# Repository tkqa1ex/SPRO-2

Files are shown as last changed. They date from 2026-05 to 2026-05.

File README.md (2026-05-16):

# SPRO-2: Motor Control & Generator Project

## 🟦 Project Overview
This repository contains the hardware designs and firmware for our university semester project (SPRO-2).

---

## 📂 Repository Structure

### 🔌 [Hardware](./motor-PCB)
The hardware is designed in **KiCad** and is split into three main modules:
* **Control Board:** The "brains" of the operation, handling logic and signal processing.
* **Generator Board:** Responsible for power generation and distribution.
* **Current Sensor Test Board:** A dedicated board for validating the current sensing circuitry before full integration.

### 💻 [Firmware](./Firmware)
*(Coming Soon)*
The firmware will handle the motor control algorithms, sensor data acquisition, and communication logic.

---

## 🛠 Tech Stack
* **PCB Design:** KiCad 10.0
* **Firmware:** C / Arduino
* **Documentation:** LaTeX

---

## 👥 Team Members
* **Alexander (tkqa1ex)**
* **David (floppy)**
* [Name 3] - [Role]

---

## 🚀 Getting Started
1. **Clone the repo:**
   ```bash
   git clone [https://github.com/tkqa1ex/SPRO-2.git](https://github.com/tkqa1ex/SPRO-2.git)

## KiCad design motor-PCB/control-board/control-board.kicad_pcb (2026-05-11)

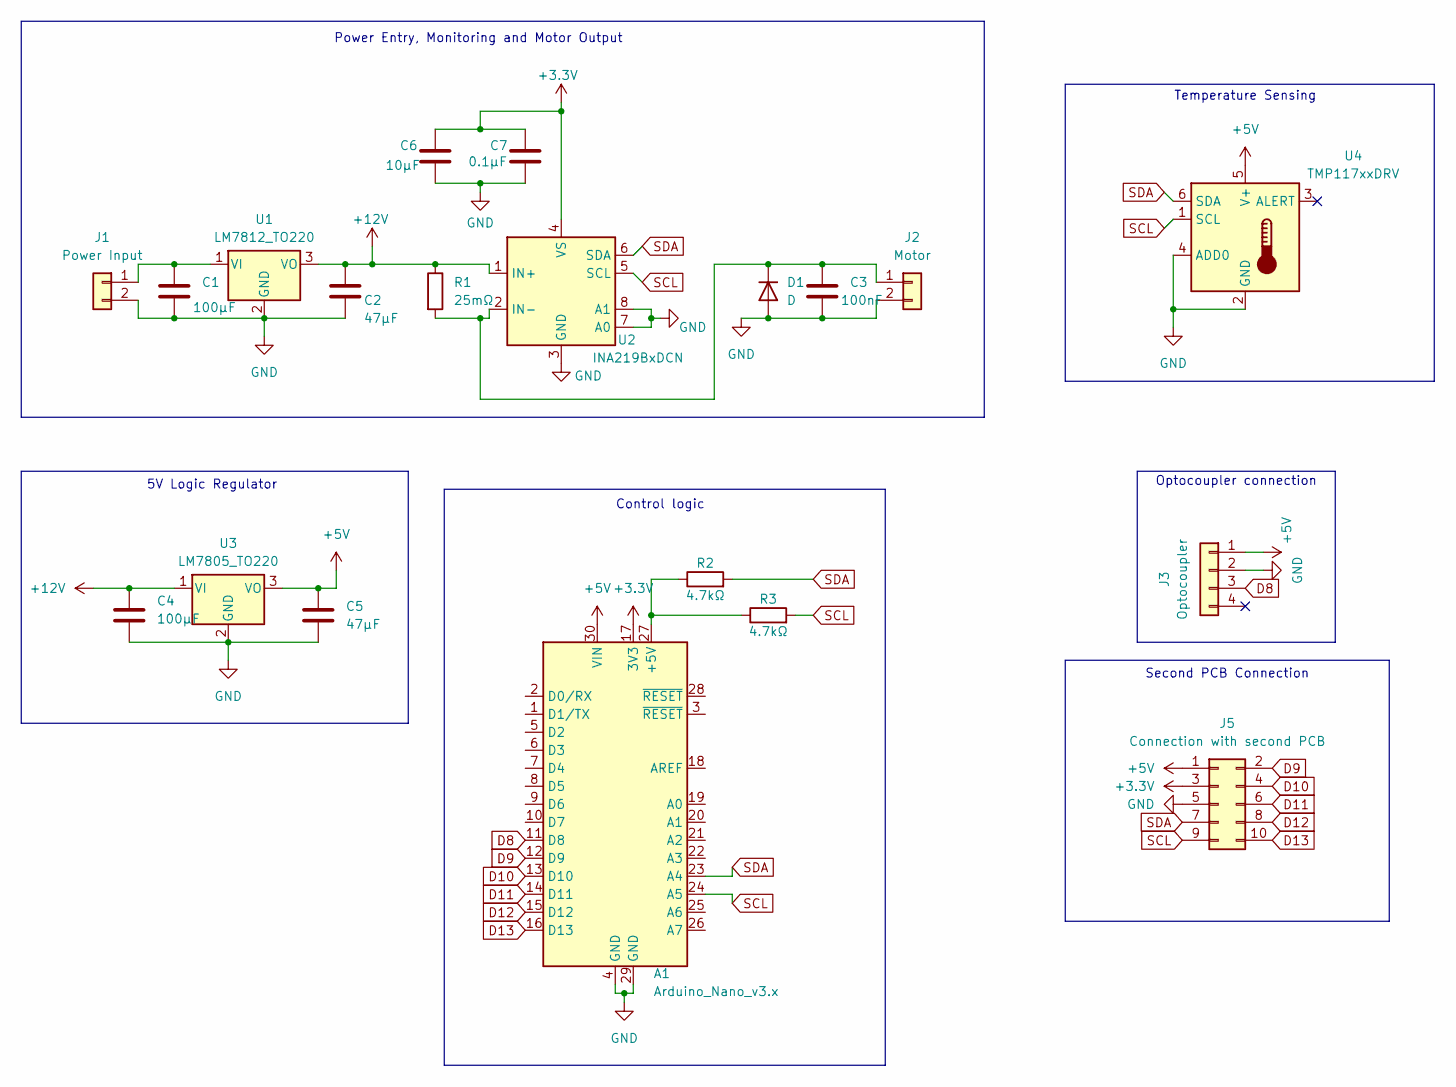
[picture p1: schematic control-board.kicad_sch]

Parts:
A1: Arduino_Nano_v3.x; Arduino_Nano
C1, C4: 100µF; CP_Radial_D8.0mm_P3.50mm
C2, C5: 47µF; CP_Radial_D6.3mm_P2.50mm
C3: 100nF; C_Disc_D5.0mm_W2.5mm_P2.50mm
C6: 10µF; CP_Radial_D5.0mm_P2.00mm
C7: 0.1µF; C_Disc_D5.0mm_W2.5mm_P2.50mm
D1: D; D_DO-41_SOD81_P10.16mm_Horizontal
J1: Power Input; TerminalBlock_CUI_TB007-508-02_1x02_P5.08mm_Horizontal
J2: Motor; TerminalBlock_CUI_TB007-508-02_1x02_P5.08mm_Horizontal
J3: Optocoupler; PinHeader_1x04_P2.54mm_Vertical
J5: Connection with second PCB; PinHeader_2x05_P2.54mm_Vertical
R1: 25mΩ; R_Axial_DIN0414_L11.9mm_D4.5mm_P15.24mm_Horizonta
R2: 4.7kΩ; R_Axial_DIN0207_L6.3mm_D2.5mm_P10.16mm_Horizontal
R3: 4.7kΩ; R_Axial_DIN0207_L6.3mm_D2.5mm_P7.62mm_Horizontal
U1: LM7812_TO220; TO-220-3_Vertical
U2: INA219BxDCN; SOT-23-8
U3: LM7805_TO220; TO-220-3_Vertical
U4: TMP117xxDRV; WSON-6-1EP_2x2mm_P0.65mm_EP1x1.6mm

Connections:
+3.3V: A1.17 (3V3), C6.1, C7.1, J5.3, U2.4 (VS)
+5V: A1.30 (VIN), C5.1, J3.1, J5.1, U3.3 (VO), U4.5 (V+)
+12V: C2.1, C4.1, R1.1, U1.3 (VO), U2.1 (IN+), U3.1 (VI)
D8: A1.11 (D8), J3.3
D9: A1.12 (D9), J5.2
D10: A1.13 (D10), J5.4
D11: A1.14 (D11), J5.6
D12: A1.15 (D12), J5.8
D13: A1.16 (D13), J5.10
GND: A1.4 (GND), A1.29 (GND), C1.2, C2.2, C3.2, C4.2, C5.2, C6.2, C7.2, D1.2 (A), J1.2, J2.2, J3.2, J5.5, U1.2 (GND), U2.3 (GND), U2.7 (A0), U2.8 (A1), U3.2 (GND), U4.2 (GND), U4.4 (ADD0)
unnamed: A1.27 (+5V), R2.1, R3.1
unnamed: C3.1, D1.1 (K), J2.1, R1.2, U2.2 (IN-)
unnamed: C1.1, J1.1, U1.1 (VI)
SCL: A1.24 (A5), J5.9, R3.2, U2.5 (SCL), U4.1 (SCL)
SDA: A1.23 (A4), J5.7, R2.2, U2.6 (SDA), U4.6 (SDA)

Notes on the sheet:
Temperature Sensing
Control logic
Optocoupler connection
Power Entry, Monitoring and Motor Output
Second PCB Connection
5V Logic Regulator

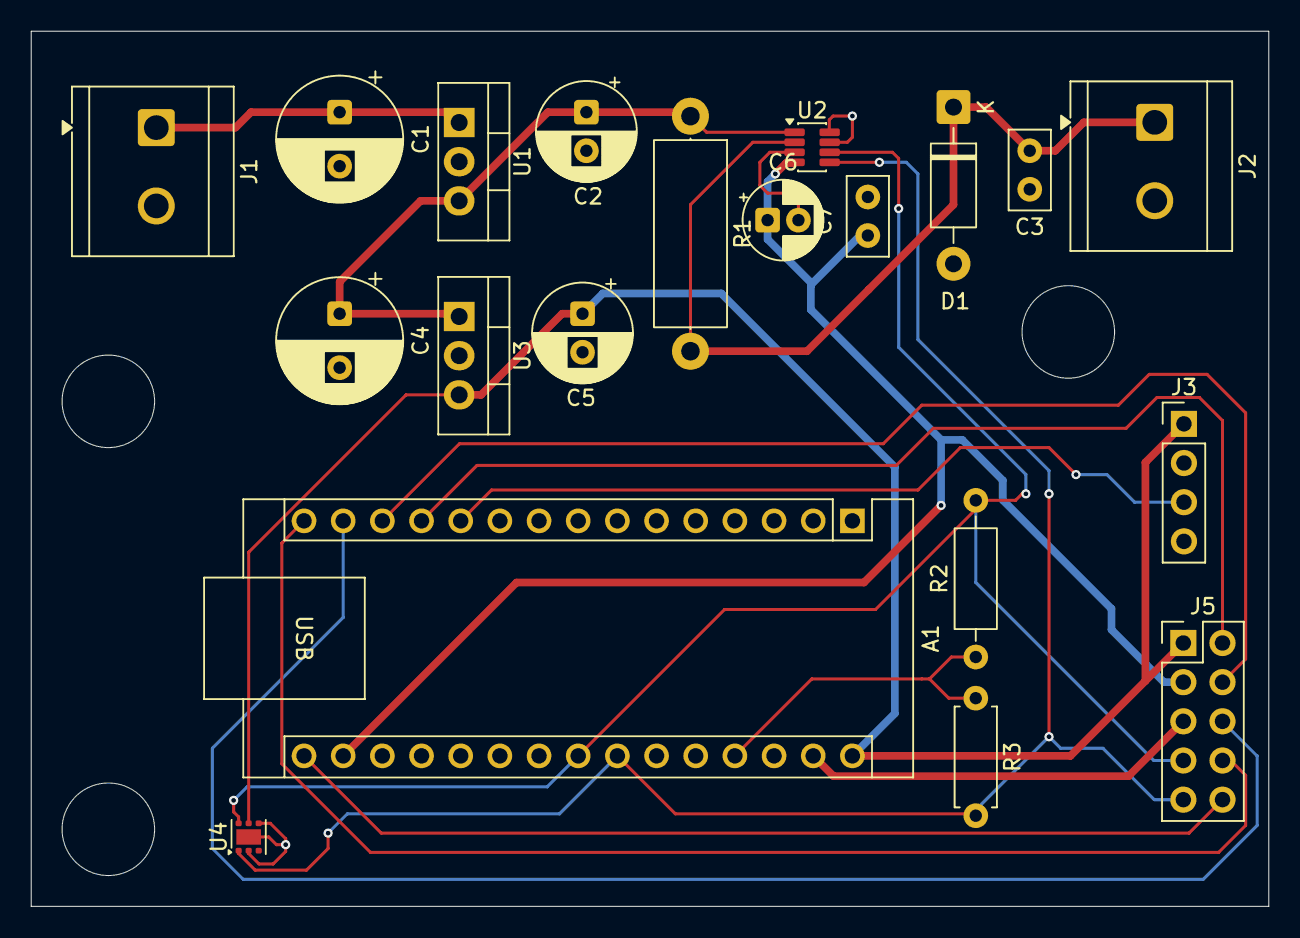
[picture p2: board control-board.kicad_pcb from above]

Board: 2 copper layers, 80.2 x 56.8 mm, 20 parts (0 on the bottom side), 15 nets.

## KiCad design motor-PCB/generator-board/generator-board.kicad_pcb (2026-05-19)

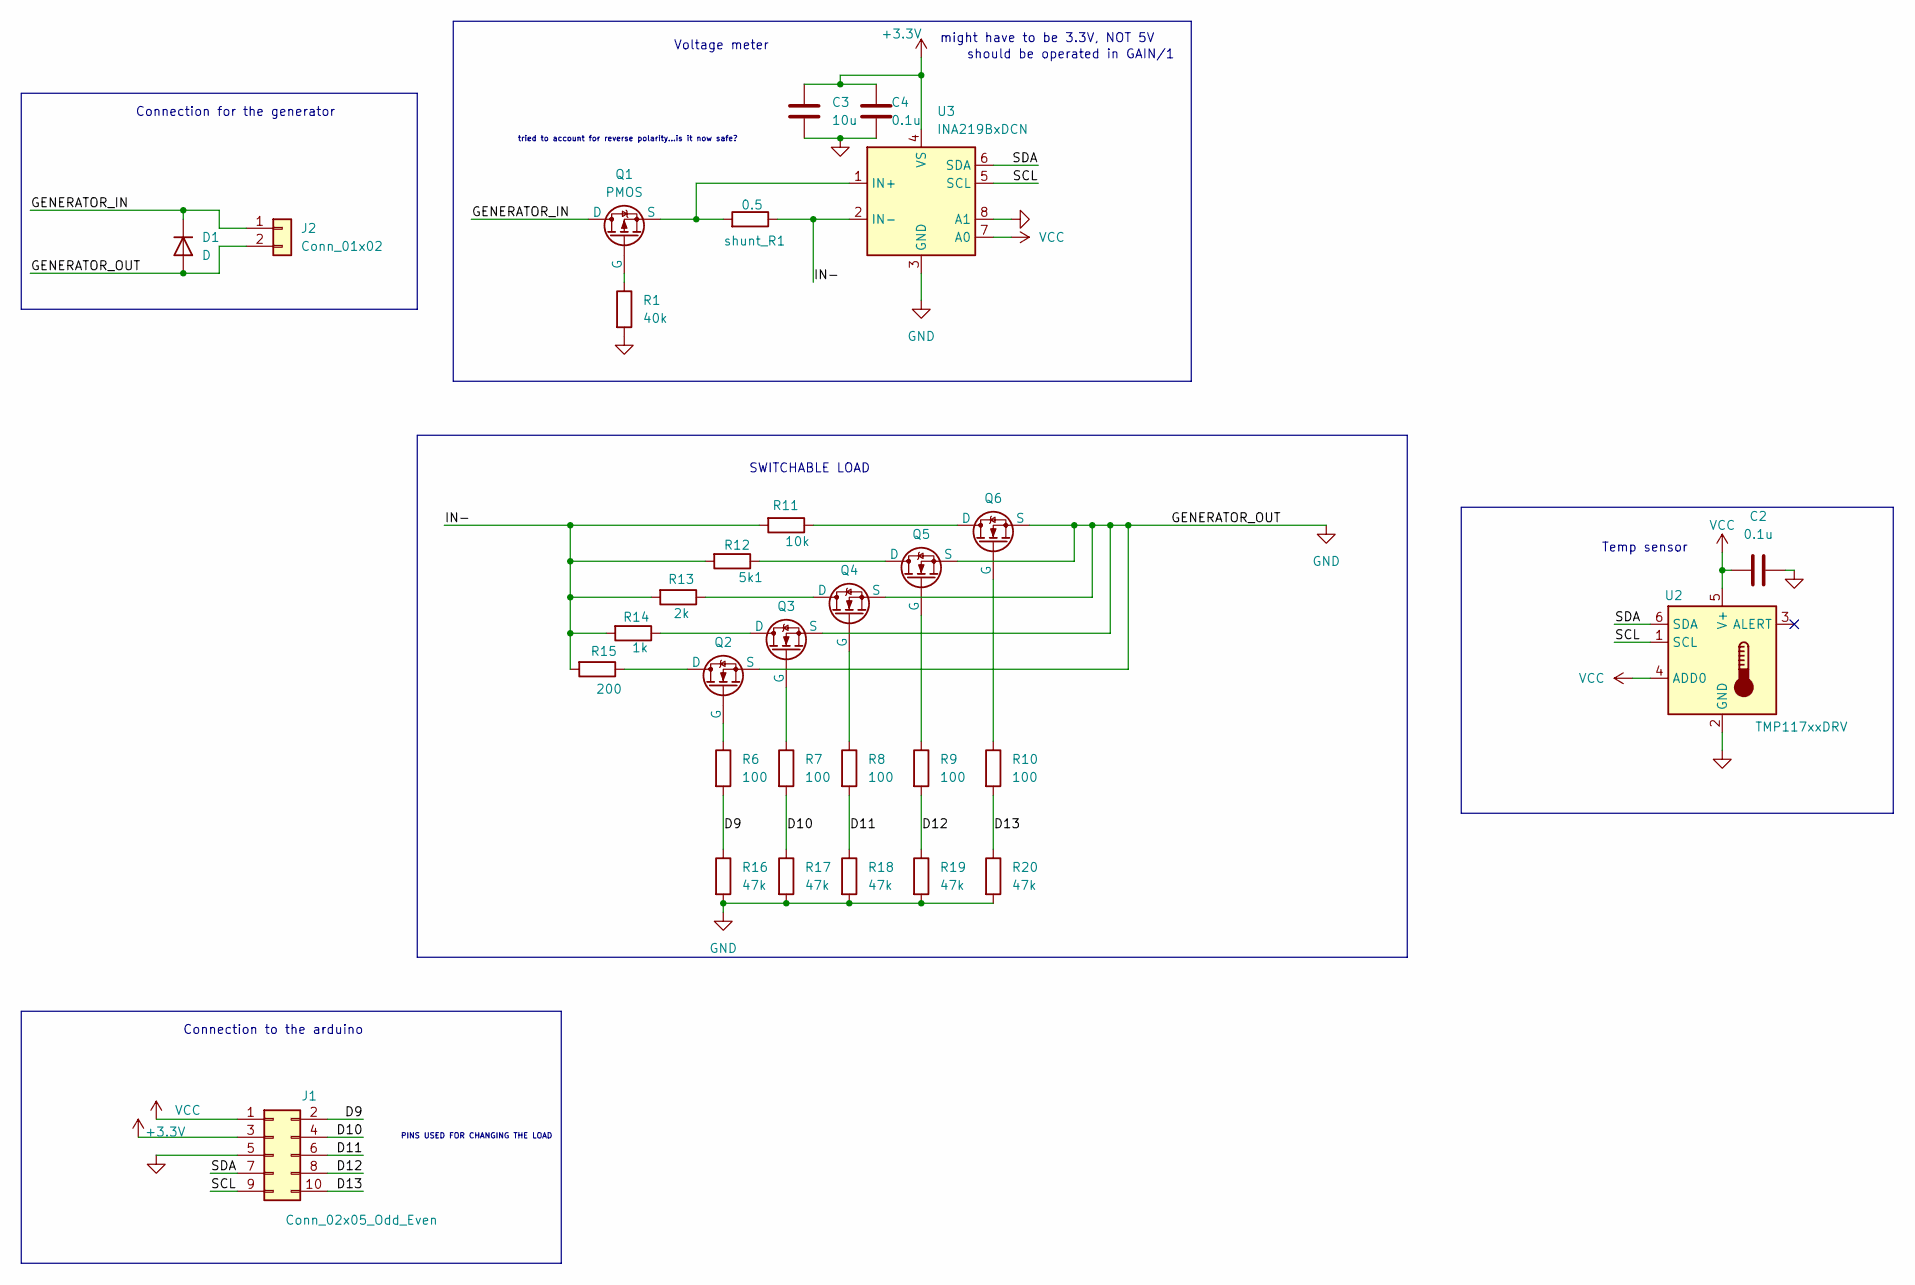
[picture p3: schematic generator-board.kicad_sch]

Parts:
C2, C4: 0.1u; CP_Radial_D10.0mm_P5.00mm
C3: 10u; CP_Radial_D10.0mm_P5.00mm
D1: D; D_DO-41_SOD81_P10.16mm_Horizontal
J1: Conn_02x05_Odd_Even; PinHeader_2x05_P2.54mm_Vertical
J2: Conn_01x02; PinHeader_1x02_P2.54mm_Vertical
Q1: PMOS; TO-220-3_Vertical
Q2, Q3, Q4, Q5, Q6: NMOS_GDS; TO-220-3_Vertical
R1: 40k; R_Axial_DIN0207_L6.3mm_D2.5mm_P10.16mm_Horizontal
R6, R7, R8, R9, R10: 100; R_Axial_DIN0207_L6.3mm_D2.5mm_P10.16mm_Horizontal
R11: 10k; R_Axial_DIN0207_L6.3mm_D2.5mm_P10.16mm_Horizontal
R12: 5k1; R_Axial_DIN0207_L6.3mm_D2.5mm_P10.16mm_Horizontal
R13: 2k; R_Axial_DIN0207_L6.3mm_D2.5mm_P10.16mm_Horizontal
R14: 1k; R_Axial_DIN0207_L6.3mm_D2.5mm_P10.16mm_Horizontal
R15: 200; R_Axial_DIN0207_L6.3mm_D2.5mm_P10.16mm_Horizontal
R16, R17, R18, R19, R20: 47k; R_Axial_DIN0207_L6.3mm_D2.5mm_P10.16mm_Horizontal
U2: TMP117xxDRV; WSON-6-1EP_2x2mm_P0.65mm_EP1x1.6mm
U3: INA219BxDCN; SOT-23-8
shunt_R1: 0.5; R_Axial_DIN0207_L6.3mm_D2.5mm_P10.16mm_Horizontal

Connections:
+3.3V: C3.1, C4.1, J1.3, U3.4 (VS)
/D9: J1.2, R6.2, R16.1
/D10: J1.4, R7.2, R17.1
/D11: J1.6, R8.2, R18.1
/D12: J1.8, R9.2, R19.1
/D13: J1.10, R10.2, R20.1
/GENERATOR_IN: D1.1 (K), J2.1, Q1.2 (D)
/IN-: R11.2, R12.2, R13.2, R14.2, R15.2, U3.2 (IN-), shunt_R1.1
/SCL: J1.9, U2.1 (SCL), U3.5 (SCL)
/SDA: J1.7, U2.6 (SDA), U3.6 (SDA)
GND: C2.2, C3.2, C4.2, D1.2 (A), J1.5, J2.2, Q2.3 (S), Q3.3 (S), Q4.3 (S), Q5.3 (S), Q6.3 (S), R1.2, R16.2, R17.2, R18.2, R19.2, R20.2, U2.2 (GND), U3.3 (GND), U3.8 (A1)
unnamed: Q1.1 (G), R1.1
unnamed: Q1.3 (S), U3.1 (IN+), shunt_R1.2
unnamed: Q2.2 (D), R15.1
unnamed: Q2.1 (G), R6.1
unnamed: Q3.2 (D), R14.1
unnamed: Q3.1 (G), R7.1
unnamed: Q4.2 (D), R13.1
unnamed: Q4.1 (G), R8.1
unnamed: Q5.2 (D), R12.1
unnamed: Q5.1 (G), R9.1
unnamed: Q6.2 (D), R11.1
unnamed: Q6.1 (G), R10.1
VCC: C2.1, J1.1, U2.4 (ADD0), U2.5 (V+), U3.7 (A0)

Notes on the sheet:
Voltage meter
tried to account for reverse polarity...is it now safe?
might have to be 3.3V, NOT 5V
Temp sensor
SWITCHABLE LOAD
Connection for the generator
should be operated in GAIN/1
Connection to the arduino
PINS USED FOR CHANGING THE LOAD

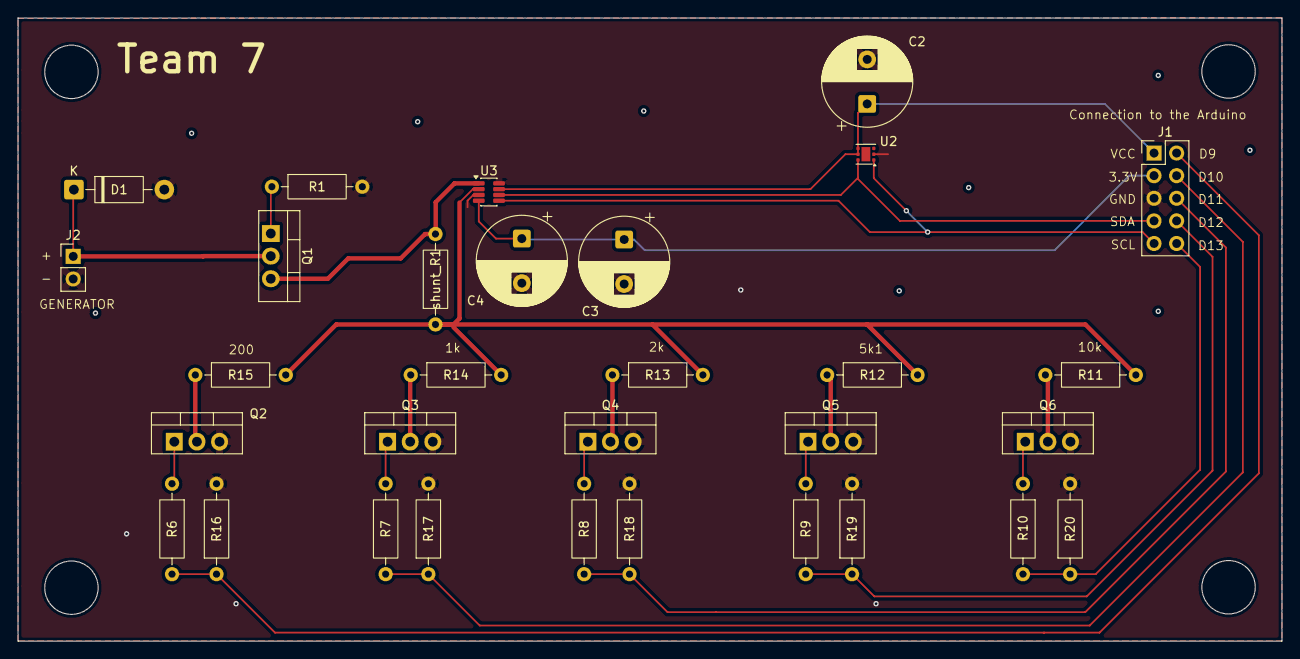
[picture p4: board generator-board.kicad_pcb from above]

Board: 2 copper layers, 142.0 x 70.0 mm, 31 parts (0 on the bottom side), 24 nets.

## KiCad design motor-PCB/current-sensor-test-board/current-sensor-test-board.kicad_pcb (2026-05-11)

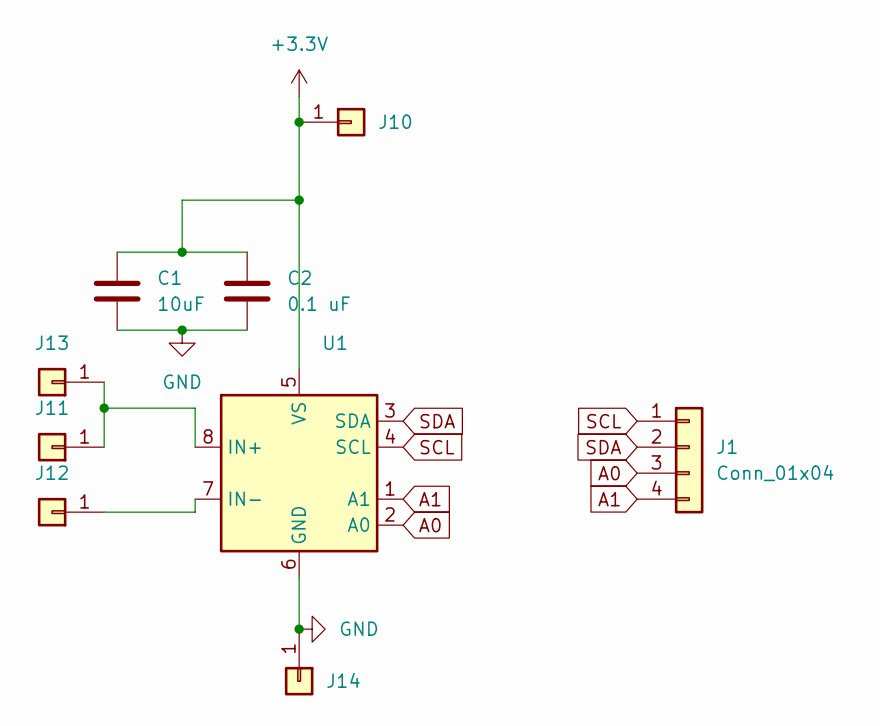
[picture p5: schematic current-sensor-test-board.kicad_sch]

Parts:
C1: 10uF; CP_Radial_D5.0mm_P2.00mm
C2: 0.1 uF; C_Disc_D5.0mm_W2.5mm_P2.50mm
J1: Conn_01x04; PinHeader_1x04_P2.54mm_Vertical
J10, J13, J14: Conn_01x01; PinHeader_1x01_P2.54mm_Vertical
J11, J12: Conn_01x01; PinSocket_1x01_P2.54mm_Vertical
U1: INA219AxD; SOIC-8_3.9x4.9mm_P1.27mm

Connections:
+3.3V: C1.2, C2.1, J10.1 (Pin_1_1), U1.5 (VS)
A0: J1.3, U1.2 (A0)
A1: J1.4, U1.1 (A1)
GND: C1.1, C2.2, J14.1 (Pin_1_1), U1.6 (GND)
unnamed: J11.1 (Pin_1_1), J13.1 (Pin_1_1), U1.8 (IN+)
unnamed: J12.1 (Pin_1_1), U1.7 (IN-)
SCL: J1.1, U1.4 (SCL)
SDA: J1.2, U1.3 (SDA)

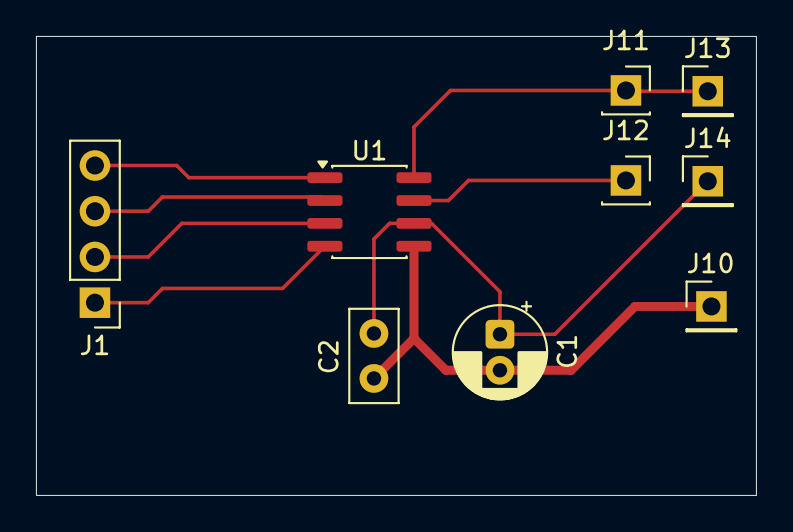
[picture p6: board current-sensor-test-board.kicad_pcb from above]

Board: 2 copper layers, 40.0 x 25.5 mm, 9 parts (0 on the bottom side), 8 nets.

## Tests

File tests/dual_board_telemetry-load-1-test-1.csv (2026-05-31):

Ctrl_Voltage_V | Ctrl_Current_mA | Ctrl_Temp_C | Gen_Voltage_V | Gen_Current_mA | Gen_Temp_C | RPM | I_mA_0 | T
1.88 | 249.2 | 27.55 | 0.02 | -0.03 | 24.52 | 4.166667 | 35.752167 | 1.325292 | 0
1.89 | 249.2 | 27.55 | 0.02 | -0.02 | 24.52 | 4.166667 | 35.752167 | 1.325663 | 0
1.9 | 250 | 27.55 | 0.02 | -0.02 | 24.52 | 4.166667 | 35.752167 | 1.325663 | 0
1.9 | 249.6 | 27.55 | 0.02 | -0.02 | 24.52 | 4.166667 | 35.752167 | 1.325663 | 0
5.19 | 336.4 | 27.55 | 4.17 | 11.34 | 24.52 | 868.75 | 39.2105 | 1.875424 | 0
7.6 | 372.8 | 27.56 | 8.6 | 33.77 | 24.52 | 1791.666667 | 42.902167 | 2.844537 | 0
8.61 | 364.4 | 27.56 | 11.08 | 48.5 | 24.52 | 2308.333333 | 44.968833 | 3.467694 | 0
8.69 | 359.6 | 27.56 | 11.27 | 50.64 | 24.52 | 2347.916667 | 45.127167 | 3.552962 | 0
10.06 | 419.2 | 27.56 | 12.33 | 52.62 | 24.52 | 2568.75 | 46.0105 | 3.659192 | 0
11.31 | 450.4 | 27.57 | 15.14 | 64.74 | 24.52 | 3154.166667 | 48.352167 | 4.195719 | 0
11.94 | 437.6 | 27.57 | 16.32 | 74.18 | 24.52 | 3400 | 49.3355 | 4.582425 | 0
11.95 | 436.4 | 27.57 | 16.51 | 74.47 | 24.52 | 3439.583333 | 49.493833 | 4.599058 | 0
11.93 | 434.8 | 27.57 | 16.53 | 74.56 | 24.52 | 3443.75 | 49.5105 | 4.603016 | 0
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

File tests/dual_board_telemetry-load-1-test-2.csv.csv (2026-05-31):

Ctrl_Voltage_V | Ctrl_Current_mA | Ctrl_Temp_C | Gen_Voltage_V | Gen_Current_mA | Gen_Temp_C | RPM | I_mA_0 | T
1.95 | 240.4 | 25.98 | 0.02 | -0.02 | 24.62 | 4.166667 | 35.752167 | 1.325663 | 0
1.94 | 240.4 | 25.98 | 0.02 | -0.02 | 24.62 | 4.166667 | 35.752167 | 1.325663 | 0
1.94 | 240.4 | 25.98 | 0.02 | -0.03 | 24.62 | 4.166667 | 35.752167 | 1.325292 | 0
1.94 | 240.4 | 25.98 | 0.02 | -0.02 | 24.62 | 4.166667 | 35.752167 | 1.325663 | 0
1.95 | 240.4 | 25.98 | 0.02 | -0.02 | 24.62 | 4.166667 | 35.752167 | 1.325663 | 0
1.95 | 240.4 | 25.97 | 0.02 | -0.03 | 24.62 | 4.166667 | 35.752167 | 1.325292 | 0
1.94 | 240.4 | 25.97 | 0.02 | -0.02 | 24.62 | 4.166667 | 35.752167 | 1.325663 | 0
1.95 | 240.4 | 25.97 | 0.02 | -0.03 | 24.62 | 4.166667 | 35.752167 | 1.325292 | 0
1.94 | 240.4 | 25.97 | 0.02 | -0.02 | 24.62 | 4.166667 | 35.752167 | 1.325663 | 0
1.96 | 241.2 | 25.97 | 0.02 | -0.03 | 24.62 | 4.166667 | 35.752167 | 1.325292 | 0
2.23 | 241.6 | 25.97 | 0.02 | -0.02 | 24.62 | 4.166667 | 35.752167 | 1.325663 | 0
9.13 | 485.2 | 25.97 | 7.78 | 47.65 | 24.62 | 1620.833333 | 42.218833 | 3.334134 | 0
9.33 | 364.4 | 25.97 | 12.1 | 54.76 | 24.62 | 2520.833333 | 45.818833 | 3.731475 | 0
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

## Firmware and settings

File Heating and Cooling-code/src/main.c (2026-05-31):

#include <stdio.h>
#include <stdbool.h>
#include <avr/io.h>
#include <util/delay.h>
#include <avr/interrupt.h>
#include <string.h>
#include "usart.h"

#define DBS_TIME (uint32_t)10000

volatile float PWM_FAN = 0.5;
volatile float PWM_HEATING_PAD = 0.25;
volatile uint32_t last_fan_button_press,last_heating_pad_button_press;
volatile uint16_t tovf_cnt,fan_adc,heating_pad_adc;
volatile uint8_t last_fan_edge = 1,last_heating_pad_edge = 1,adc_conversion_complete;
volatile uint8_t change_pwm_fan = 1,change_pwm_heating_pad = 1;

// implement 2 pwms (hai T0 si T2 sa aiba aceeasi durata)
// check they work
// add PCINT to arduino and check with buttons
// beers?

void arduino_init(void);

// not used but nice to have in case u want to implement a PID controller
void set_heating_pad_PWM(float pwm);
void set_fan_PWM(float pwm);
void adjust_PWM();
void read_new_ADC();
uint16_t read_adc(int);

int main() {
    arduino_init();
    while (1) {
        // read the new voltages to figure out position of the pot
        // and change the pwm accordingly
        read_new_ADC();
        adjust_PWM();
        _delay_ms(300);
    }
}

// same structure for the PCINT2 ISR
ISR(PCINT0_vect) {
    // the real time at the time this interrupt was triggered
    uint32_t actual_time = ((uint32_t)tovf_cnt << 16) + TCNT1;

    // find what type of change has occured (1 means rising, 0 is falling)
    uint8_t current_edge = 0;
    if (PINB & (1 << PB1)) {
        current_edge = 1;
    }

    // only process the interrupt when the edge actually changes
    // noise can sometimes toggle the signal extremely quickly.
    //
    // for example
    // - last valid edge was HIGH
    // - noise briefly causes HIGH -> LOW -> HIGH within a few us
    // the temporary LOW transition is ignored by the debounce filter because it
    // occurs too soon after the previous HIGH edge. However, the second HIGH may
    // arrive later and still trigger a pin-change interrupt even though the
    // logical edge state never truly changed.
    if (last_fan_edge != current_edge) {
        // if it is on a rising edge and the time since the last press is more than the DBS_TIME 
        if (last_fan_edge == 1 && actual_time - last_fan_button_press >= DBS_TIME) {
            last_fan_button_press = actual_time;
            if (change_pwm_fan == 0) {
                change_pwm_fan = 1;
                OCR0B = PWM_FAN * 0xFF;
                TCCR0B |= (1 << CS01) | (1 << CS00); 
            } else {
                change_pwm_fan = 0;
                OCR0B = 0;
                TCCR0B = 0;
            }
        }
        last_fan_edge = current_edge;
    }
}

ISR(PCINT2_vect) {
    uint32_t actual_time = ((uint32_t)tovf_cnt << 16) + TCNT1;
    uint8_t current_edge = 0;
    if (PIND & (1 << PD6)) {
        current_edge = 1;
    }
    if (last_heating_pad_edge != current_edge) {
        if (last_heating_pad_edge == 1 && actual_time - last_heating_pad_button_press >= DBS_TIME) {
            last_heating_pad_button_press = actual_time;
            if (change_pwm_heating_pad == 0) {
                change_pwm_heating_pad = 1;
                TCCR2B |= (1 << CS22);
                OCR2B = PWM_HEATING_PAD * 0xFF;
            } else {
                change_pwm_heating_pad = 0;
                OCR2B = 0;
                TCCR2B = 0;
            }
        }
        last_heating_pad_edge = current_edge;
    }
}

ISR(TIMER1_OVF_vect) {
    ++tovf_cnt;
}

uint16_t read_adc(int channel) {
    ADMUX &= ~(0x0F);
    ADMUX |= channel;
    _delay_ms(10);
    ADCSRA |= (1 << ADSC);
    while (ADCSRA & (1 << ADSC));

    return ADC;
}
// gonna use ADC0-1 -> PC0-1 (A0-1)
void read_new_ADC() {
    fan_adc = read_adc(0);
    heating_pad_adc = read_adc(1);
}

void adjust_PWM() {
    // x - 100
    // ADC - 2^10
    set_fan_PWM(fan_adc / 1024.0);
    set_heating_pad_PWM(heating_pad_adc / 1024.0);
    //printf("FAN PWM: %.2f\n HEATING PAD PWM: %.2f \n\n",PWM_FAN,PWM_HEATING_PAD);
}

void set_heating_pad_PWM(float pwm) {
    PWM_HEATING_PAD = pwm;
    if (change_pwm_heating_pad) {
        OCR2B = 0xFF * pwm;
    }
}

void set_fan_PWM(float pwm) {
    PWM_FAN = pwm;
    if (change_pwm_fan) {
        OCR0B = 0xFF * pwm;
    }
}

void enable_ADC() {
    ADMUX |= (1 << REFS0);
    ADCSRA |= (1 << ADEN);
    ADCSRA |= (1 << ADPS2 | 1 << ADPS1 | 1 << ADPS0);
    // ADC has a resolution of 10 bits with 5V as VREF => we can use a 1k pot to change the pwm, nice :)
}

void init_timer() {
    // init timer1 with prescalar of 8 to get
    // 32ms
    TCCR1B |= (1 << CS11);
    //TOVF niterrupt
    TIMSK1 |= (1 << TOIE1);
}

void set_up_pwms() {
    // use fast pwm + toggle on compare match
    // gonna use OC0B with clear on equal
    // setting for OC0B -> PD5, CHECKED, click of button also CHECKED
    DDRD |= (1 << PD5);
    OCR0B = 0xFF * PWM_FAN;
    TCCR0A |= (1 << COM0B1) | (1 << WGM01) | (1 << WGM00);
    // scalar of 64 so every overflow is 1ms 
    TCCR0B |= (1 << CS01) | (1 << CS00); 
    

    // setting for 0C2B -> PD3, CHECKED
    DDRD |= (1 << PD3);
    OCR2B = 0xFF * PWM_HEATING_PAD;
    TCCR2A |= (1 << COM2B1) | (1 << WGM21 | 1 << WGM20);
    TCCR2B |= (1 << CS22);
}

void set_up_edge_detection() {
    // gonna use PCINT22 (PD6-D6),PCINT1(PB1-D9) 
    // 1 -> FAN (PB1)
    // 22 -> HEATING PAD (PD6)
    DDRB &= ~(1 << PB1);
    DDRD &= ~(1 << PD6);

    PORTB |= (1 << PB1);
    PORTD |= (1 << PD6);
    // enable the 2 and 0 group
    PCICR |= (1 << PCIE2) | (1 << PCIE0);
    PCMSK2 |= (1 << PCINT22);
    PCMSK0 |= (1 << PCINT1);
}

void arduino_init() {
    // initialise the communication to the pc for debugging purposes mainly
    uart_init();
    io_redirect();

    enable_ADC();
    init_timer();
    set_up_pwms();
    set_up_edge_detection();
    // enable interrupts
    sei();
}

// can use the pins to the generator to track the i2c bus
// the current has 16 bit contents



 

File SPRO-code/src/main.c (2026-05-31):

#include <stdio.h>
#include <stdbool.h>
#include <avr/io.h>
#include <util/delay.h>
#include <avr/interrupt.h>
#include <string.h>
#include "usart.h"
#include "i2cmaster.h"
#include "constants.h"
#include "INA219.h"
#include "TMP117.h"

volatile uint16_t counter;
volatile uint64_t timer;

// flag which makes sure the sampling rate is mantained 
volatile uint8_t take_data,stop_sending_data;

// for the data from the sensors
float bus_voltage_control,bus_voltage_generator,current_control,current_generator,
ambiental_temperature_control,ambiental_temperature_generator;



// start timer with precalar of 64 to get 1ms per counter overflow
void init_timer2();

// configure all the sensors through I2C
void init_outsiders();
void OPEN(pin LOAD);
void system_init(pin LOAD);

// used to get the needed data
void take_measurement();
void get_TMP117_CONTROL();
void get_TMP117_GENERATOR();
void get_INA219_GENERATOR();
void get_INA219_CONTROL();

// send data to the PC which reads it with matlab
void send_data_to_matlab();

int main() {
    // initialise the system whilst also opening pin D9
    system_init(D9);
    while (1) {
        // whenever the sampling time is reached take_data is set true by
        // a timer2 interrupt
        if (take_data) {
            // get all the measurements from the sensors
            take_measurement();

            // send everything through usart to 
            send_data_to_matlab();
            take_data = false;
        }
    }
}

void send_data_to_matlab() {
    // Sending to the PC data as follows
    // voltage control, current control, control temp
    // voltage generator, current generator, gen temp
    printf("%.2f %.2f %.2f %.2f %.2f %.2f %d\n",bus_voltage_control,current_control,ambiental_temperature_control,
        bus_voltage_generator,current_generator,ambiental_temperature_generator,
        stop_sending_data);

    // FOR DEBUGGING
    // printf("Control: bus voltage: %f V current: %f mA temperature: %fC\n",bus_voltage_control,current_control,ambiental_temperature_control);
    // printf("Generator: bus voltage: %f V current: %f mA temperature: %fC\n",bus_voltage_generator,current_generator,ambiental_temperature_generator);
    // printf("Loop flag: %u\n\n",stop_sending_data);
}

// init sensors
void init_outsiders() {
    INA219_INIT_CONTROL();
    INA219_INIT_GENERATOR();
    TMP117_INIT(TMP117_CONTROL);
    TMP117_INIT(TMP117_GENERATOR);
    // give enough time for components to wake up and transients to magically disappear, to fade away like my hopes and dreams :)))
    // just to make sure they have the time to update, shuold be much less but we arent rly in a worry
    _delay_ms(5); 
}

// get readings from the INA219 sensor from the generator
void get_INA219_GENERATOR() {
    bus_voltage_generator = GET_BUS_VOLTAGE(INA219_GENERATOR);
    current_generator = GET_CURRENT_GENERATOR();
}

// get readings from the TMP117 sensor from the generator
void get_TMP117_GENERATOR() {
    ambiental_temperature_generator = TMP117_readTemperature(TMP117_GENERATOR);
}

// get readings from the TMP117 sensor from the control
void get_TMP117_CONTROL() {
    ambiental_temperature_control = TMP117_readTemperature(TMP117_CONTROL);
}

// get readings from the INA219 sensor from the control
void get_INA219_CONTROL() {
    bus_voltage_control = GET_BUS_VOLTAGE(INA219_CONTROL); // seems to be overshoot by 0.2V
    current_control = GET_CURRENT_CONTROL();
}


// get the data from the sensors to the mcu
void take_measurement() {
    get_INA219_CONTROL();
    get_INA219_GENERATOR();
    get_TMP117_CONTROL();
    get_TMP117_GENERATOR();
}

void init_timer2() {
    // SCALAR OF 64, lasts 1ms
    // works in normal mode (it is the default) and its just a counter that gets back to 0 once it reaches max (0xFF)
    TIMSK2 |= (1 << TOIE2);
    TCCR2B |= (1 << CS22); 
}

void system_init(pin LOAD) {
    // enable interrupts
    sei(); 

    // debug + sending to matlab
    uart_init();
    io_redirect();

    // enable i2c communication
    i2c_init(); 

    // enable the load
    OPEN(LOAD);
    
    // init sensors
    init_outsiders();    
    
    // timer go brrr
    init_timer2();
}

void OPEN(pin LOAD) {
    // open the D9-D13 pin (PB1-5) resistor
    DDRB |= (1 << (LOAD + 1));
    PORTB |= (1 << (LOAD + 1));
}

// interrupts used for time counting
ISR(TIMER2_OVF_vect) {
    // every count is 1ms
    counter++;
    timer++;
    // to ensure the sampling rate
    if (counter == SAMPLING_RATE) {
        counter = 0;
        take_data = true;
    }
    if (timer == TESTING_TIME) {
        stop_sending_data = 1;
    }
}

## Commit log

2026-05-11 Initial commit: Added PCB folders and project structure
    [control-board.kicad_pcb, control-board.kicad_sch, current-sensor-test-board.kicad_pcb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]
2026-05-17 added a missing capacitor in the control-board. Added pins to be able to control the heating pad and fan and text. In the generator changed the transistor layout and also added text
    [control-board.kicad_pcb, control-board.kicad_sch, generator-board.kicad_pcb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]
2026-05-18 forgot to change the layout of the pmos so fixed that
    [generator-board.kicad_pcb, generator-board.kicad_sch]
2026-05-19 Just forgot to update the ground mask :)
    [control-board.kicad_pcb, generator-board.kicad_pcb]
2026-05-23 Add files via upload
    added the code for the 2nd arduino to control the heating pad and the fan
2026-05-25 Added the optocoupler functionality + finished the functions
    Now we just gotta figure out the current readings for the generator
2026-05-27 Current code finally works
2026-05-27 Final Control-Board
    [control-board.kicad_pcb, control-board.kicad_sch]
2026-05-29 Final Code
    added timer for the duration of the test
2026-05-31 Add files via upload
    Forgot to make the adc not change anymore after a button press
2026-05-31 Checked the ml communication with timers
2026-05-31 Data from the tests
    [dual_board_telemetry-load-1-test-1.csv, dual_board_telemetry-load-1-test-2.csv.csv, dual_board_telemetry-load-1-test-3.csv.csv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]
